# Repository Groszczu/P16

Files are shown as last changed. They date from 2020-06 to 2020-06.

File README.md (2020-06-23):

# Pad do gry Don't Starve
## Efekt końcowy

<p align="center">
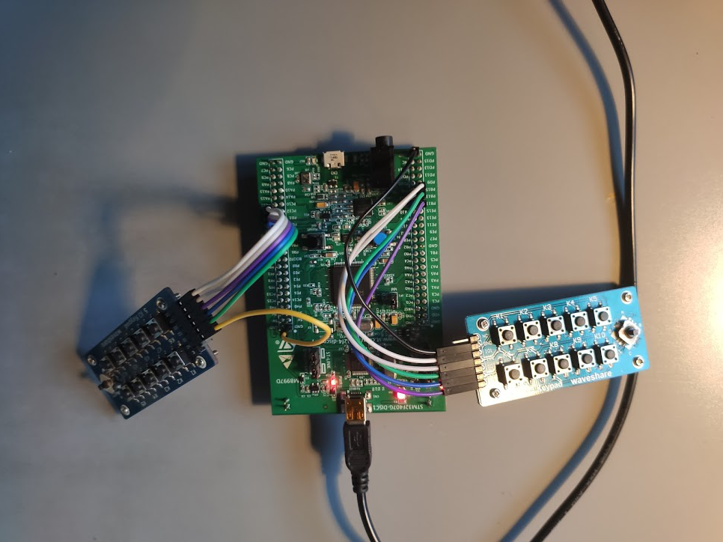
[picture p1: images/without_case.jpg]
without-case
  
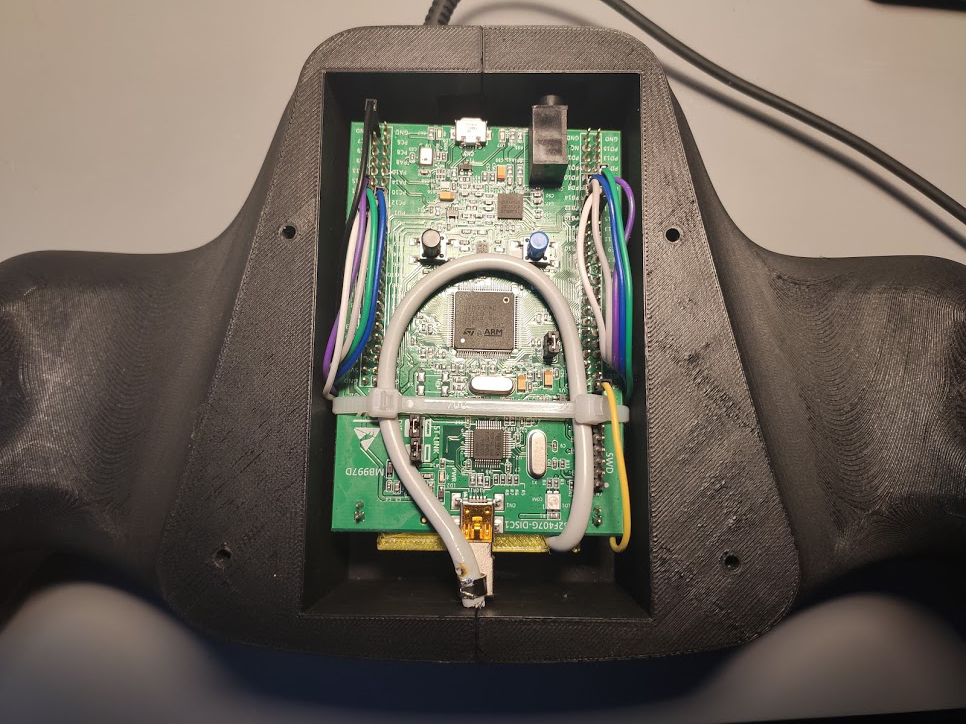
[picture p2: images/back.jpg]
back
  
  front
</p>

### [Efekt w grze Don't Starve](https://drive.google.com/file/d/1L8Kr0ft3-i-alJvvkAMZOxpQ4YpjElGc/view?usp=sharing)

## O projekcie
### Celem projektu było stworzenie kontrolera kompatybilnego z grą Don't Starve
### Do Realizacj kontrolera wykorzystano:
* Mikrokontoler STM32F407G-DISC1
* 2x Moduł 5 IO Keypad (700646947690), [schemat](https://www.waveshare.com/w/upload/f/fb/5-IO-Keypad-Schematic.pdf)
* Powerbank zasilający mikrokontroler

Software programu został napisany w języku C.</br>
Obudowa oraz przyciski zostały wydrukowane przy użyciu drukarki 3D.

Dane o stanie przycisków oraz joysticków są przesyłane do podłączonego urządzenia, w sześciu bajtach, zgodnie ze schematem:

<p align="center">
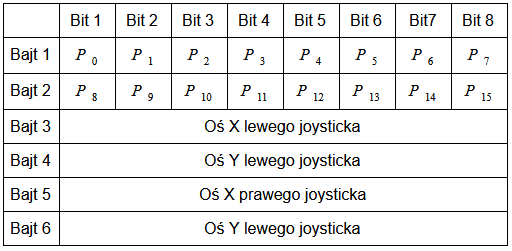
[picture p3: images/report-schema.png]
report-schema
  
</p>

Informacja o schemacie przesyłanego raportu została zakodowana przy pomocy następującego deskryptora USB:

```c
  /* USER CODE BEGIN 0 */
		  0x05, 0x01,                //USAGE_PAGE (Generic Desktop)
		  0x09, 0x05,                //USAGE (Game Pad)
		  0xa1, 0x01,                //COLLECTION (APPLICATION)
		  0xa1, 0x00,                   //COLLECTION (Physical)
		  0x05, 0x09,                   //USAGE_PAGE (Button)
		  0x19, 0x01,                   //USAGE_MINIMUM (Button1)
		  0x29, 0x18,                   //USAGE_MAXIMUM (Button 24)
		  0x15, 0x00,                   //LOGICAL_MINIMUM (0)
		  0x25, 0x01,                   //LOGICAL_MAXIMUM(1)
		  0x95, 0x18,                   //REPORT_COUNT (24)
		  0x75, 0x01,                   //REPORT_SIZE (1)
		  0x81, 0x02,                   //INPUT(Data, Var, Abs)
		  0x05, 0x01,                   //USAGE_PAGE (Generic Desktop)
		  0x09, 0x30,                   //USAGE (X)
		  0x09, 0x31,                   //USAGE (Y)
		  0x09, 0x32,                   //USAGE (Z)
		  0x09, 0x33,                   //USAGE (Rx)
		  0x15, 0x81,                   //LOGICAL_MINIMUM(-127)
		  0x25, 0x7f,                   //LOGICAL_MAXIMUM(127)
		  0x75, 0x08,                   //REPORT_SIZE(8)
		  0x95, 0x04,                   //REPORT_COUNT(4)
		  0x81, 0x02,                   //INPUT(Data,Var,Abs)
		  0xc0,                     //END_Collection
  /* USER CODE END 0 */
  0xC0    /*     END_COLLECTION	             */
```

Raport jest wysyłany do urządzenia po wykryciu wciśnięcia przycisku lub wychylenia drążka.

## Konfiguracja
### Konfiguracja pinów STM32

Do obsługi modułów 5 IO Keypad wykorzystano po 5 pinów:
* Piny PB11-PB15 - lewy moduł (GPIO)
* Piny PD0-PD3 oraz PD6 - prawy moduł (GPIO)

Piny wykorzystane do obsługi USB HID:
* PA11 i PA12

<p align="center">
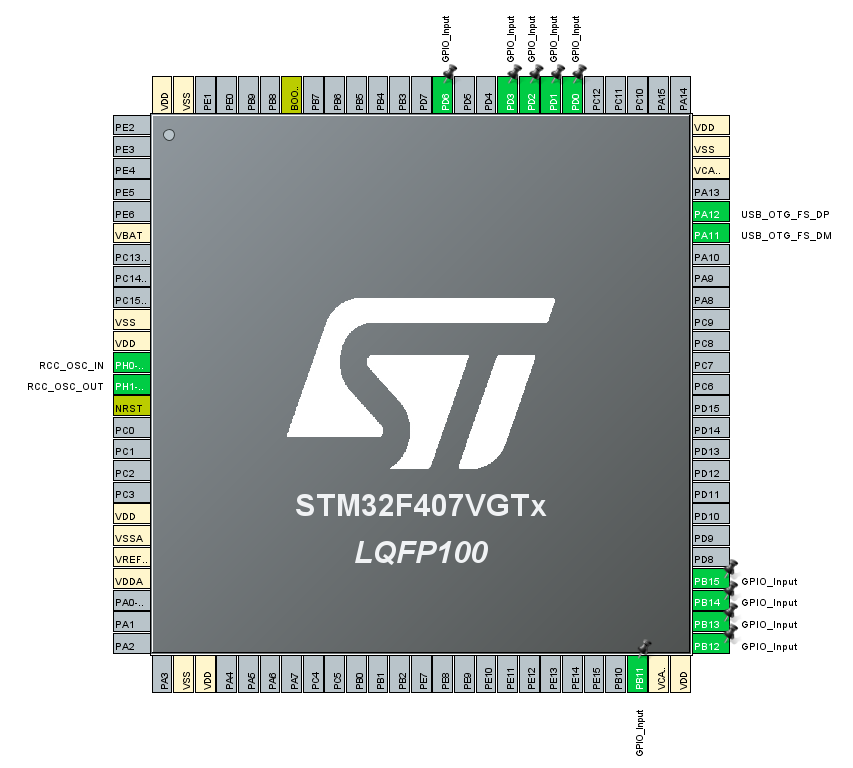
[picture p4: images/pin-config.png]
pin-config
  
</p>

### Konfiguracja Big Picture 

Konfiguracje przycisków przeprowadzono wykorzystując oprogramowanie Big Picture dostępne w platformie Steam.

#### Kontroler wykryty w Big Picture

<p align="center">
  in-big-picture
</p>

#### Przykładowa konfiguracja przycisków w Big Picture

<p align="center">
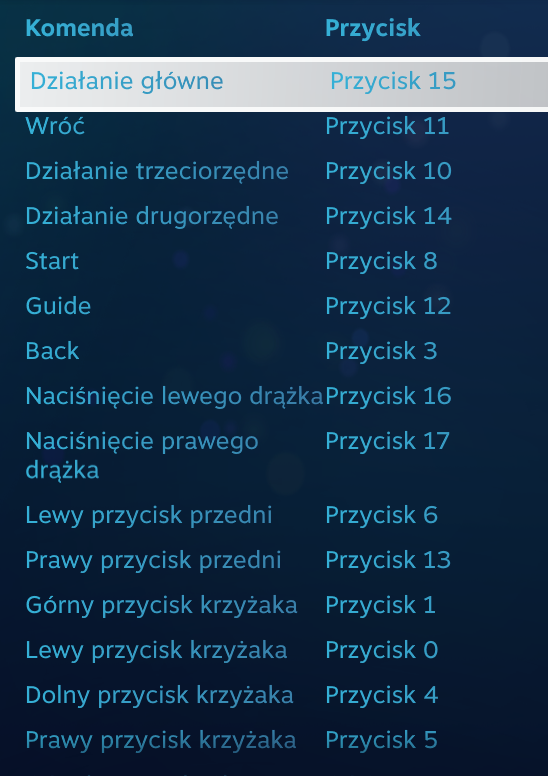
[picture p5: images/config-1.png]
config-1
  
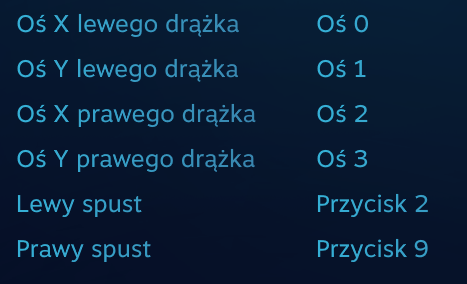
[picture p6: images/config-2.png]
config-2
  
</p>

## Autorzy
* Roch Goszczyński
* Artur Jackowiak
> 2020 PUT

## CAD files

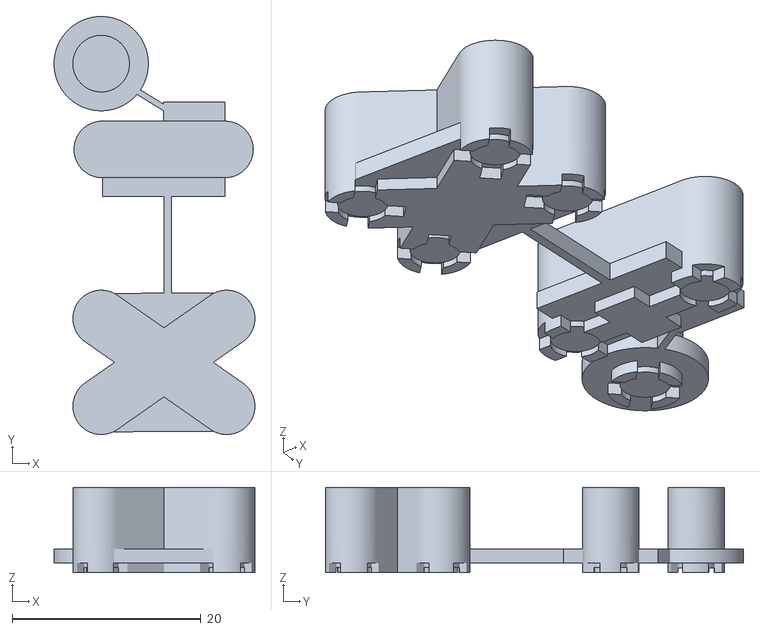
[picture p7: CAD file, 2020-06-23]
case_models/buttons.stl
21.3 x 44.3 x 9.01

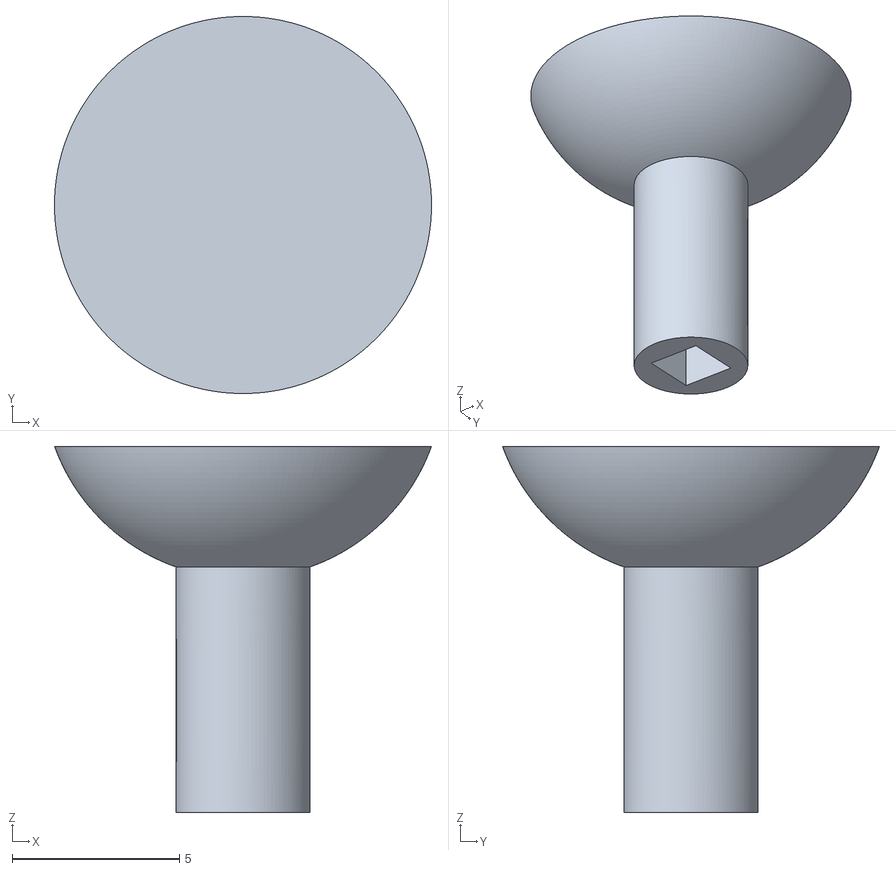
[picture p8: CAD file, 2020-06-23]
case_models/joystick.stl
11.3 x 11.3 x 11.0

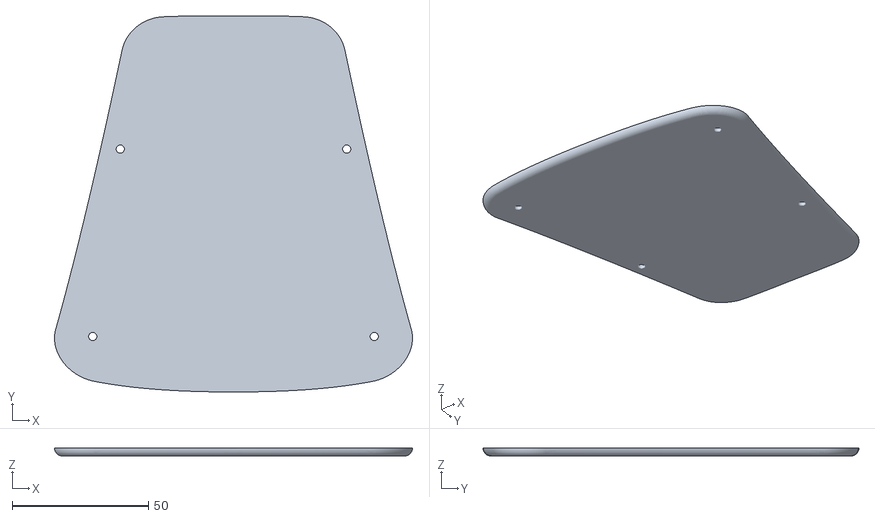
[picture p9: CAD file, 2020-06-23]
case_models/cover.stl
131.3 x 137.8 x 3.00

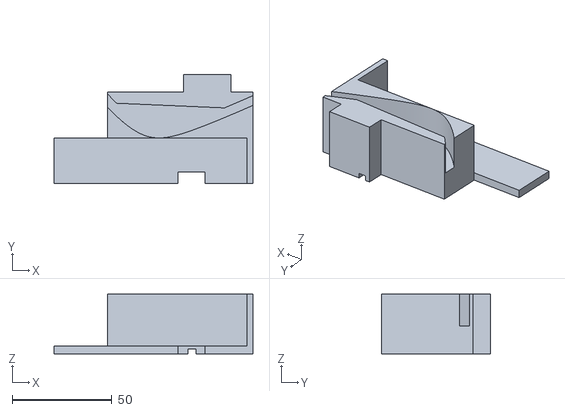
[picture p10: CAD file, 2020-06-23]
case_models/powerbank.stl
100.0 x 55.0 x 30.0

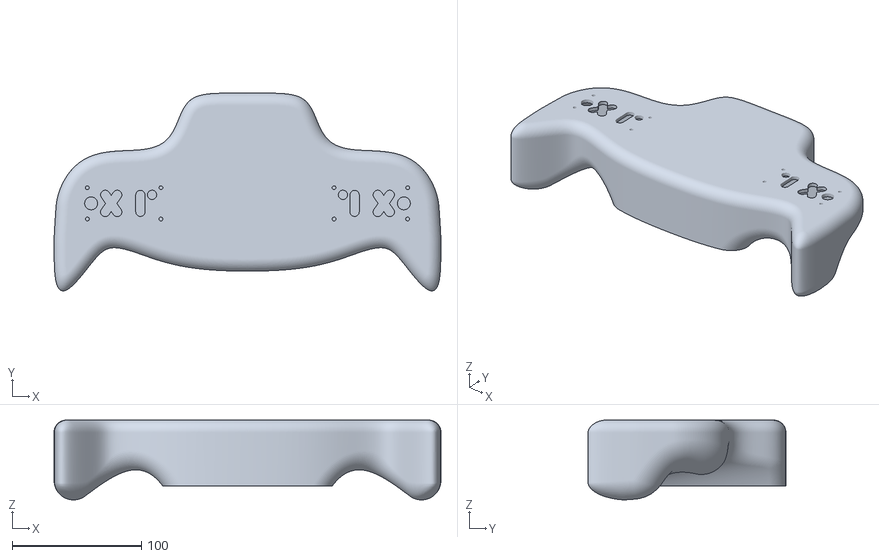
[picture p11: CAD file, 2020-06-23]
case_models/pad.stl
299.6 x 153.1 x 61.7

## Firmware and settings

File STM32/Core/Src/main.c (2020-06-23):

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

/* Includes ------------------------------------------------------------------*/
#include "main.h"
#include "usb_device.h"

/* USER CODE BEGIN Includes */
#include "usbd_customhid.h"
#include "5IO_Keypad.h"
#include "Types.h"
/* USER CODE END Includes */

/* USER CODE BEGIN PD */
#define SEND_BUFFER_SIZE 7
/* USER CODE END PD */


/* USER CODE BEGIN PV */
extern USBD_HandleTypeDef hUsbDeviceFS;

struct GamepadReport_t {
	uint16_t buttons_16;
	uint8_t buttons_8;
	int8_t left_x;
	int8_t left_y;
	int8_t right_x;
	int8_t right_y;
};
typedef struct GamepadReport_t GamepadReport_t;

uint8_t dataSendBuffer[SEND_BUFFER_SIZE];
// global flag for detecting user input
Bool CHANGED = false;
GamepadReport_t gamepadReport;
/* USER CODE END PV */

void SystemClock_Config(void);
static void MX_GPIO_Init(void);
/* USER CODE BEGIN PFP */


void ResetGamepadReport() {
	gamepadReport.buttons_16 = 0;
	gamepadReport.buttons_8 = 0;
	gamepadReport.left_x = 0;
	gamepadReport.left_y = 0;
	gamepadReport.right_x = 0;
	gamepadReport.right_y = 0;
}

void PrepareSendBuffer(uint8_t *buffer, GamepadReport_t *gamepadReport) {
	buffer[0] = (uint8_t) (gamepadReport->buttons_16 & 0x00FF);
	buffer[1] = (uint8_t) (gamepadReport->buttons_16 >> 8);
	buffer[2] = gamepadReport->buttons_8;
	buffer[3] = gamepadReport->left_x;
	buffer[4] = gamepadReport->left_y;
	buffer[5] = gamepadReport->right_x;
	buffer[6] = gamepadReport->right_y;
}

void GetUserInput() {
	const uint8_t JOYSTICK_VALUE = 64;

	uint32_t leftKeypadValue = KeypadScan(LEFT);
	uint32_t rightKeypadValue = KeypadScan(RIGHT);

	Bool changedLeft = true;
	Bool changedRight = true;

	switch(leftKeypadValue) {
		case 0: changedLeft = false; break;
		case 1: gamepadReport.left_x = -JOYSTICK_VALUE; break; // LEFT
		case 2: gamepadReport.left_y = -JOYSTICK_VALUE; break;  // UP
		case 3: gamepadReport.buttons_8 |= 1U << 0; break; // PRESS
		case 4: gamepadReport.left_y = JOYSTICK_VALUE; break; // DOWN
		case 5: gamepadReport.left_x = JOYSTICK_VALUE; break;  // RIGHT
		case 6: gamepadReport.buttons_16 |= 1U << 7; break;
		case 7: gamepadReport.buttons_16 |= 1U << 6; break;
		case 8: changedLeft = false; break;
		case 9: gamepadReport.buttons_16 |= 1U << 5; break;
		case 10: gamepadReport.buttons_16 |= 1U << 4; break;
		case 11: gamepadReport.buttons_16 |= 1U << 3; break;
		case 12: gamepadReport.buttons_16 |= 1U << 2; break;
		case 13: changedLeft = false; break;
		case 14: gamepadReport.buttons_16 |= 1U << 1; break;
		case 15: gamepadReport.buttons_16 |= 1U << 0; break;
	}

	switch(rightKeypadValue) {
		case 0: changedRight = false; break;
		case 1: gamepadReport.right_x = -JOYSTICK_VALUE; break; // LEFT
		case 2: gamepadReport.right_y = -JOYSTICK_VALUE; break;  // UP
		case 3: gamepadReport.buttons_8 |= 1U << 1; break; // PRESS
		case 4: gamepadReport.right_y = JOYSTICK_VALUE; break; // DOWN
		case 5: gamepadReport.right_x = JOYSTICK_VALUE; break;  // RIGHT
		case 6: gamepadReport.buttons_16 |= 1U << 8; break;  // K1
		case 7: gamepadReport.buttons_16 |= 1U << 9; break; // K2
		case 8: changedRight = false; break; // K3
		case 9: gamepadReport.buttons_16 |= 1U << 10; break; // K4
		case 10: gamepadReport.buttons_16 |= 1U << 11; break; // K5
		case 11: gamepadReport.buttons_16 |= 1U << 12; break; // K6
		case 12: gamepadReport.buttons_16 |= 1U << 13; break; // K7
		case 13: changedRight = false; break; // K8
		case 14: gamepadReport.buttons_16 |= 1U << 14; break; // K9
		case 15: gamepadReport.buttons_16 |= 1U << 15; break; // K10
	}

	// if no button has been pressed (or button without any functionality)
	if (changedLeft == false && changedRight == false) {
		// and last time this function was called there user input was detected
		if (CHANGED == true) {
			// reset buffer values and send empty buffer to the device
			ResetGamepadReport();
			PrepareSendBuffer(dataSendBuffer, &gamepadReport);

			USBD_CUSTOM_HID_SendReport(&hUsbDeviceFS, dataSendBuffer, SEND_BUFFER_SIZE);
			CHANGED = false;
		}
		//else return without sending buffer
		return;
	}

	// if some buttons were pressed set CHANGED flag to true
	CHANGED = true;
}


/* USER CODE END PFP */

/**
  * @brief  The application entry point.
  * @retval int
  */
int main(void)
{
  /* MCU Configuration--------------------------------------------------------*/

  /* Reset of all peripherals, Initializes the Flash interface and the Systick. */
  HAL_Init();

  /* Configure the system clock */
  SystemClock_Config();

  /* Initialize all configured peripherals */
  MX_GPIO_Init();
  MX_USB_DEVICE_Init();
  /* USER CODE BEGIN 2 */
  ResetGamepadReport();
  /* USER CODE END 2 */

  /* Infinite loop */
  /* USER CODE BEGIN WHILE */
  while (1)
  {
	  GetUserInput();

	  if (CHANGED == true) {
		  PrepareSendBuffer(dataSendBuffer, &gamepadReport);

	  	  USBD_CUSTOM_HID_SendReport(&hUsbDeviceFS, dataSendBuffer, SEND_BUFFER_SIZE);
	  	  ResetGamepadReport();

	  	HAL_Delay(50);
	 }

    /* USER CODE END WHILE */

    /* USER CODE BEGIN 3 */
  }
  /* USER CODE END 3 */
}

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


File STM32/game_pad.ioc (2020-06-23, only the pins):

Mcu.UserName=STM32F407VGTx
PA11.Signal=USB_OTG_FS_DM
PA12.Signal=USB_OTG_FS_DP
PB11.Signal=GPIO_Input
PB12.Signal=GPIO_Input
PB13.Signal=GPIO_Input
PB14.Signal=GPIO_Input
PB15.Signal=GPIO_Input
PD0.Signal=GPIO_Input
PD1.Signal=GPIO_Input
PD2.Signal=GPIO_Input
PD3.Signal=GPIO_Input
PD6.Signal=GPIO_Input
PH0-OSC_IN.Signal=RCC_OSC_IN
PH1-OSC_OUT.Signal=RCC_OSC_OUT

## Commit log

2020-03-30 configure basic custom HID device (using USER button)
2020-04-04 configure keypad buttons (joystick not working)
    [5IO_Keypad.c, 5IO_Keypad.h, game_pad.ioc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]
2020-04-04 reconfigure joystick, add reversed joystick controls
    [5IO_Keypad.c, 5IO_Keypad.h]
2020-04-06 add second (right) keypad configuration. Parallel reading from both keypads doesn't work
    [5IO_Keypad.c, 5IO_Keypad.h, game_pad.ioc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]
2020-04-28 Add support for holding buttons down
2020-05-25 Configure global CHANGED flag to ignore not used buttons
2020-06-09 Add case models and change buttons configuration
    [buttons.stl, cover.stl, joystick.stl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]
2020-06-23 Add pin config image

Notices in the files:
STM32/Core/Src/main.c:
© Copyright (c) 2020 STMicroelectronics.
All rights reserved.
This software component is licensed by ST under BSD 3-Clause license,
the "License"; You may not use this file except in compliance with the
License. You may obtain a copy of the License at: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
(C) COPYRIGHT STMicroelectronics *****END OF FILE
